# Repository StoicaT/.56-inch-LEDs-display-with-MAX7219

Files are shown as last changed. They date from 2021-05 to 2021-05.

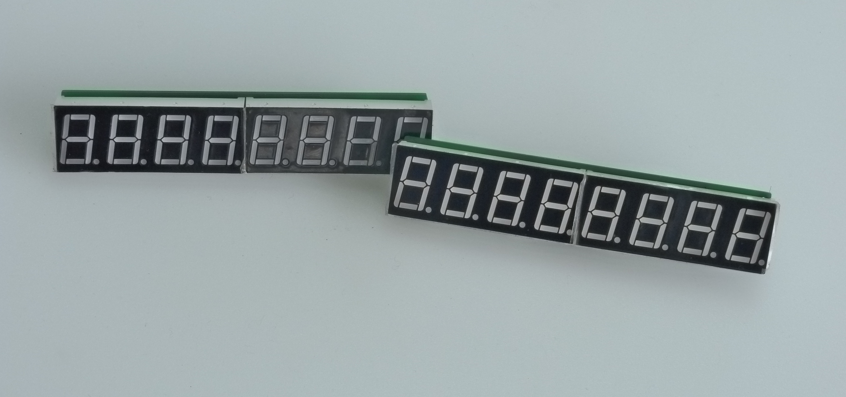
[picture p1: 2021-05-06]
P1040260.JPG

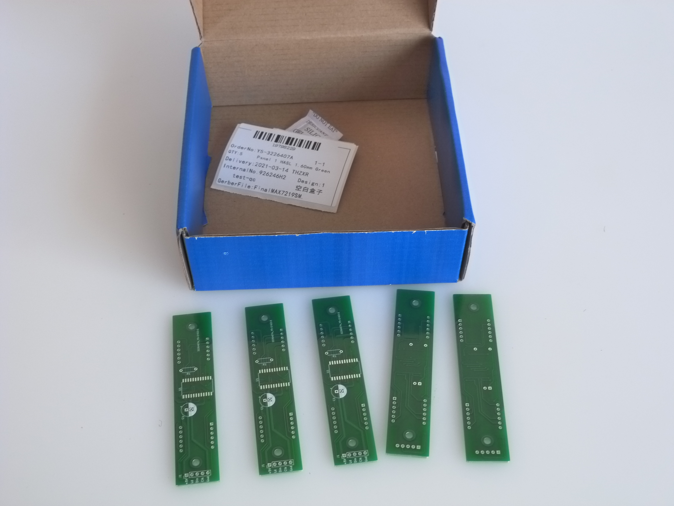
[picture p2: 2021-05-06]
P1040204.JPG

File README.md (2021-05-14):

# .56-inch-LEDs-display-with-MAX7219
Building and testing  a module with 8 digits LEDs drived by MAX7219. 

This project aims to build and test an 8-digit LED module, 0.56 inches, drived by MAX2719. There are 2 variants, THT and SMD. 
PCBs are designed with KiCad program and are given together with Wiring Diagram and assembly details.
There is also a test program, which will be uploaded on an Arduino board and will allow a detailed visual check of the module.
More on:https://www.instructables.com/56inch-LEDs-Display-With-MAX7219/

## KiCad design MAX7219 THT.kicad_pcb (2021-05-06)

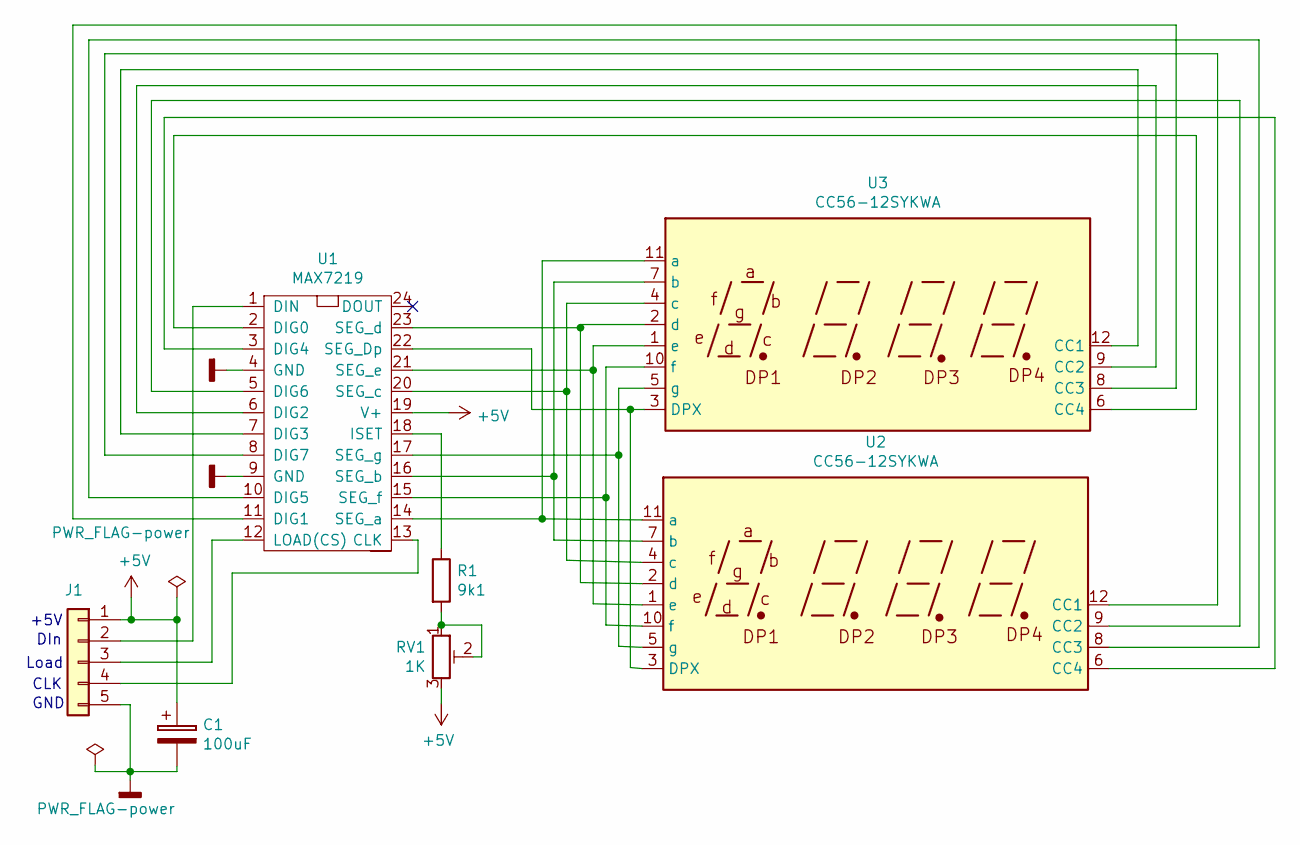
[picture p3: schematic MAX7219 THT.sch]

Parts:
C1: 100uF; CP_Radial_D7.5mm_P2.50mm
J1: Conn_01x05; PinHeader_1x05_P2.54mm_Vertical
R1: 9k1; R_Axial_DIN0207_L6.3mm_D2.5mm_P10.16mm_Horizontal
RV1: 1K; Potentiometer_Piher_PT-6-V_Vertical
U1: MAX7219
U2, U3: CC56-12SYKWA; CA56-12SYKWA

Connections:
+5V: C1.1, J1.1, RV1.3, U1.19 (V+)
GNDD: C1.2, J1.5, U1.4 (GND), U1.9 (GND)
unnamed: J1.2, U1.1 (DIN)
unnamed: J1.3, U1.12 (LOAD(CS))
unnamed: J1.4, U1.13 (CLK)
unnamed: R1.1, U1.18 (ISET)
unnamed: R1.2, RV1.1, RV1.2
unnamed: U1.2 (DIG0), U3.6 (CC4)
unnamed: U1.3 (DIG4), U2.6 (CC4)
unnamed: U1.5 (DIG6), U2.9 (CC2)
unnamed: U1.6 (DIG2), U3.9 (CC2)
unnamed: U1.7 (DIG3), U3.12 (CC1)
unnamed: U1.8 (DIG7), U2.12 (CC1)
unnamed: U1.10 (DIG5), U2.8 (CC3)
unnamed: U1.11 (DIG1), U3.8 (CC3)
unnamed: U1.14 (SEG_a), U2.11 (a), U3.11 (a)
unnamed: U1.15 (SEG_f), U2.10 (f), U3.10 (f)
unnamed: U1.16 (SEG_b), U2.7 (b), U3.7 (b)
unnamed: U1.17 (SEG_g), U2.5 (g), U3.5 (g)
unnamed: U1.20 (SEG_c), U2.4 (c), U3.4 (c)
unnamed: U1.21 (SEG_e), U2.1 (e), U3.1 (e)
unnamed: U1.22 (SEG_Dp), U2.3 (DPX), U3.3 (DPX)
unnamed: U1.23 (SEG_d), U2.2 (d), U3.2 (d)

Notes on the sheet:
+5V
GND
CLK
DIn
Load

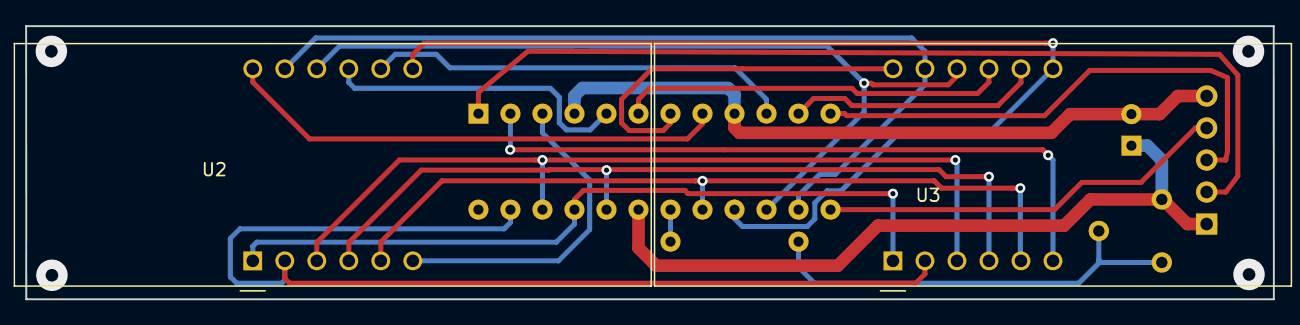
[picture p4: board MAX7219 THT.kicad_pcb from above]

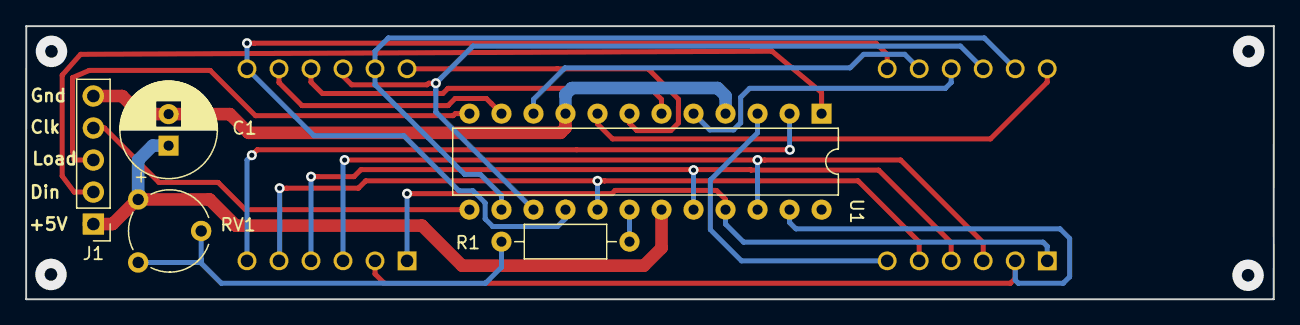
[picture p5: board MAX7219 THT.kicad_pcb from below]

Board: 2 copper layers, 99.0 x 21.7 mm, 7 parts (5 on the bottom side), 23 nets.

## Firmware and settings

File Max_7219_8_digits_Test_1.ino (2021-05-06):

/*Designed by Stoica Tudor, Apr 2021. Rew. May 2021.
This is a test program for an 8-digit 7-segment LED display with MAX7219, based on the LedControl.h library. */

#include <LedControl.h>

LedControl lc=LedControl(5,3,4,1);//We define the object:Din, Clk, Load, 1XMAX7219
# define del 500

char CHR[]= "0123456789ABCDEFHLP-._ ";//We define a character array that contains all 
                                     //the ASCII characters defined in the LedControl.h library. 
byte j=0;

void setup() {                           
lc.setIntensity(0,15);// Set the brightness to maximum value 
}

void loop() {
  
lc.shutdown(0,true);

  //We turn on all the LEDs on the display
  //It is only a soft setting, no LED will light up on the
  // display because it has previously been switched to shutdown.
  
  for(byte i=0 ;i<8 ; i++){
  lc.setChar(0,i,CHR[8],true);}
 
 //shut down/wakeup test
 
for(byte i=0 ;i<2 ; i++){

  lc.shutdown(0,true);
   delay(del);
  lc.shutdown(0,false);//Now we turn on all the LEDs on the display.
  delay(del);
}//When leave this segment of the program, the display will be in a wakeup state.

//Intesity test
for(byte i=0 ;i<16 ; i++){
lc.setIntensity(0,i);
delay(del/2);
}

lc.clearDisplay(0);//blanking display
delay(del);

//Decimal Points Test 
//We will turn successively, from right to left Decmal Points.

for(byte i=0 ;i<8 ; i++){
   lc.setChar(0,i,CHR[22],true);
   delay(del);
}
delay(del);

lc.clearDisplay(0);//blanking display
delay(del);

// LEDs segments test.
//We will light successively, from left to right, 
//the first 8 characters defined in the CHR matrix.
//Then we will scroll until all the characters 
//in the CHR array are displayed.

while(j<16){
  for(int i=7; i>-1; i--){
     lc.setChar(0,i,CHR[j],false);
     j=j+1;
    // delay(del);
    }
    j=j-7;
     delay(2*del);
   }
   j=0;
   delay(del);
   
   lc.clearDisplay(0);//blanking display

  for(byte i=0 ;i<8 ; i++){ //We will display --------- (8 times the character -)
                            //which shows the end of the test.
  lc.setChar(0,i,CHR[19],false);}
delay(2*del);
}
